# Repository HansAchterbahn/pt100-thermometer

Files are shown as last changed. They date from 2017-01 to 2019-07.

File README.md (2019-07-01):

# pt100-thermometer
_Entwicklungsdaten für ein einfaches elektronisches Thermometer_  

Die Entwicklungsdaten in diesem Repro werden auf meinem Blog https://aetzenloetenprogrammieren.blogspot.com genauer beschrieben.  

## Messprinzip

Abbildung: Messprinzip der Schaltung

## Foto der fertigen Platine

Foto: Gefertigte Platine mit Anschlüssen
Foto: Nahaufnahme der Platine

## Schaltplan

Abbildung: Schaltplan

## Boardlayout

Abbildung: Boardlayout

## Verzeichnisstruktur

* Datenblätter  
 -- AD620.pdf  
 -- TS914.pdf  
* Layout  
 * Eagle  
  -- PT100-SensorPCB008.brd  
  -- PT100-SensorPCB008.sch  
  -- PT100-SensorPCB008-Board.pdf  
  -- PT100-SensorPCB008-Schaltplan.pdf  
 * Fritzing(Breadboard)  
   -- Thermometer-PT100-fritzing.fzz  
   -- Thermometer-PT100-fritzing.png  
* Simulation  
 * LTSpice  
   -- Thermometer-PT100-LTSpice.asc  
   -- Thermometer-PT100-LTSpice.png  
 * Mathematica  
   -- PT100Kennlinie.cdf  
   -- PT100Kennlinie.png  

## Verwendete Programme

__Schaltplan, Leiterplattenlayout und Breadbord:__

Eagle - Erstellen von Schaltplan und Leiterplattenlayout  
http://www.autodesk.com/products/eagle/overview  

Fritzing - Erstellen des Breadbords  
http://fritzing.org/home/  

__Simulation__

LTSpice - Simulation des Schaltplans  
http://www.linear.com/designtools/software/#LTspice  

Mathematica - Animation der Temperaturkennlinie (Kann mit dem kostenlosen Wolfram CDF Player abgespielt werden)  
http://www.wolfram.com/mathematica/  
https://www.wolfram.com/cdf-player/

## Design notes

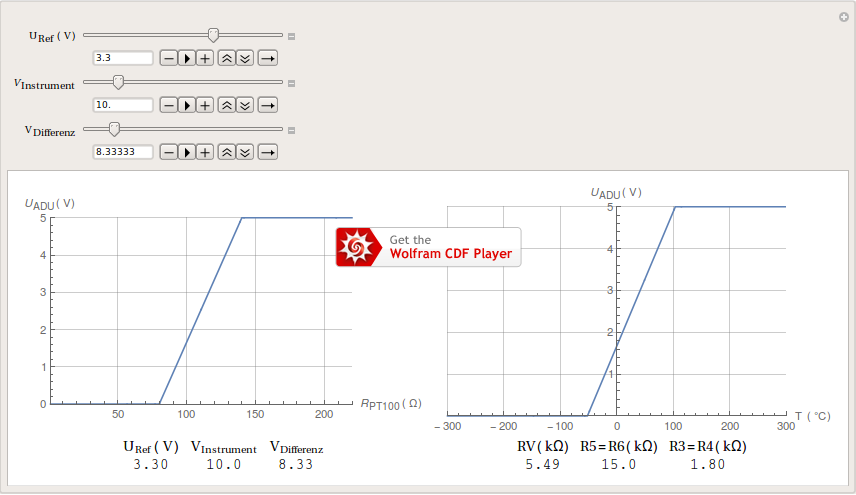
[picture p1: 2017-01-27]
Simulation/Mathematica/PT100Kennlinie.png

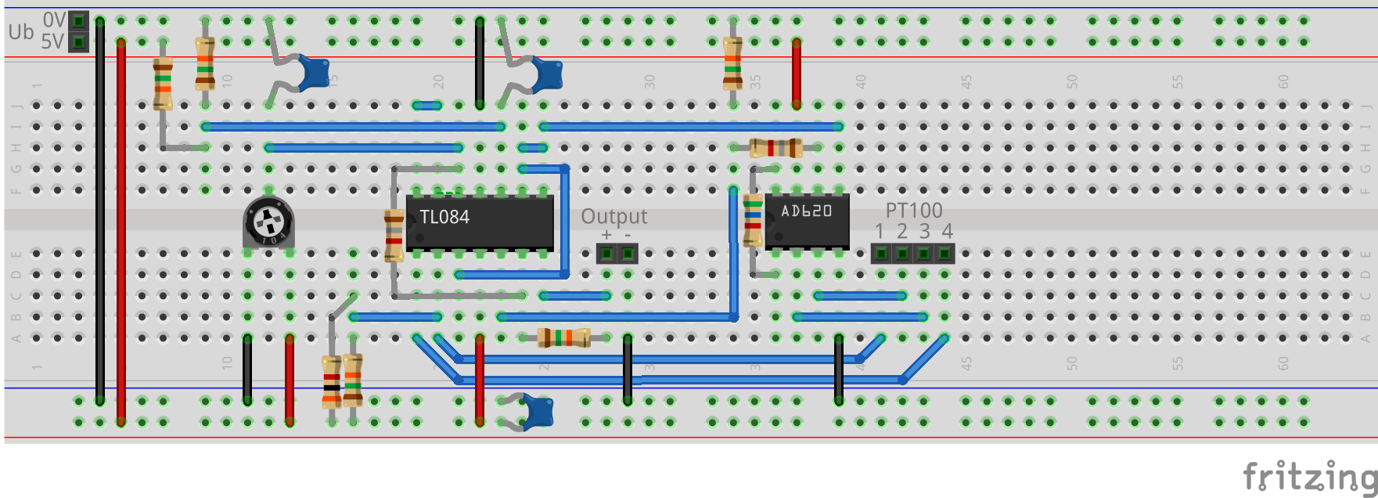
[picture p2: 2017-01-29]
Layout/Fritzing-Breadboard/Thermometer-PT100-Fritzing.png

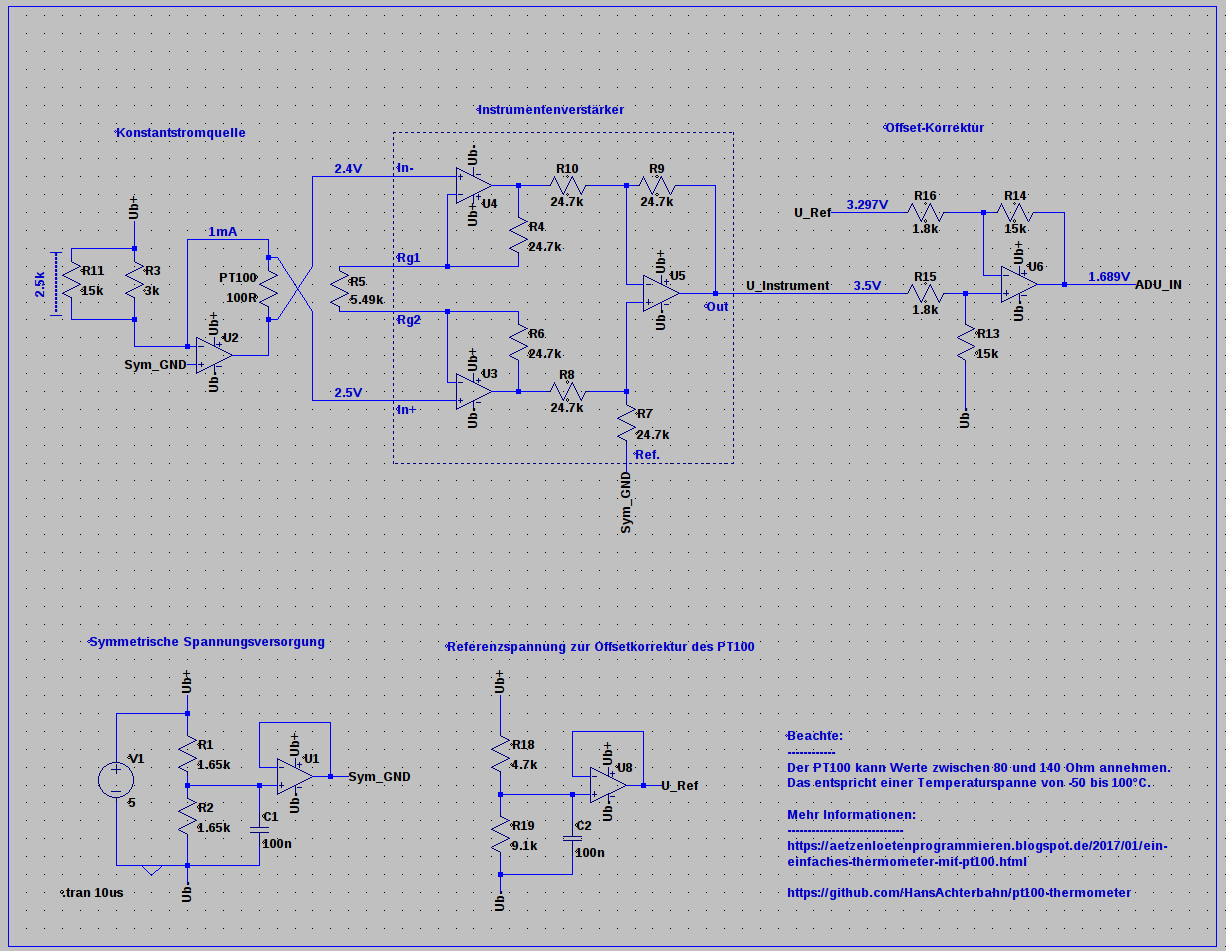
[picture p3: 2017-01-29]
Simulation/LTSpice/Thermometer-PT100-LTSpice.png

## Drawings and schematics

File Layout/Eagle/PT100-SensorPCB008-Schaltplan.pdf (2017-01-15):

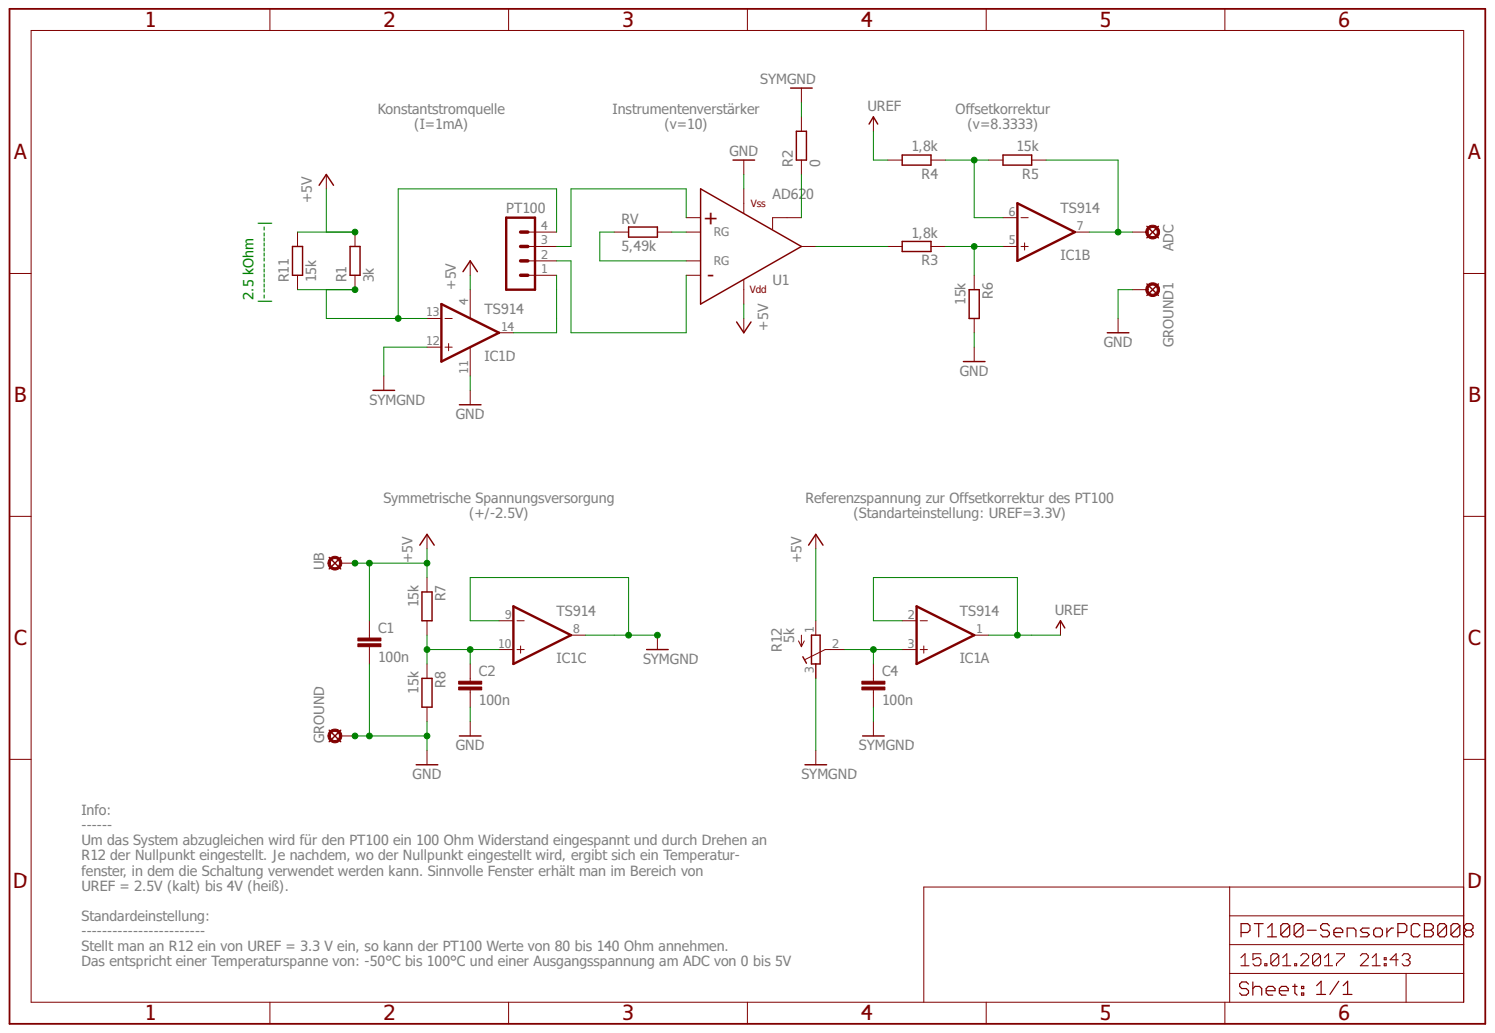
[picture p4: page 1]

SYMGND

Referenzspannung zur Offsetkorrektur des PT100

Info: ------ Um das System abzugleichen wird für den PT100 ein 100 Ohm Widerstand eingespannt und durch Drehen an R12 der Nullpunkt eingestellt. Je nachdem, wo der Nullpunkt eingestellt wird, ergibt sich ein Temperatur-

fenster, in dem die Schaltung verwendet werden kann. Sinnvolle Fenster erhält man im Bereich von UREF = 2.5V (kalt) bis 4V (heiß). Standardeinstellung: ------------------------ Stellt man an R12 ein von UREF = 3.3 V ein, so kann der PT100 Werte von 80 bis 140 Ohm annehmen. Das entspricht einer Temperaturspanne von: -50°C bis 100°C und einer Ausgangsspannung am ADC von 0 bis 5V

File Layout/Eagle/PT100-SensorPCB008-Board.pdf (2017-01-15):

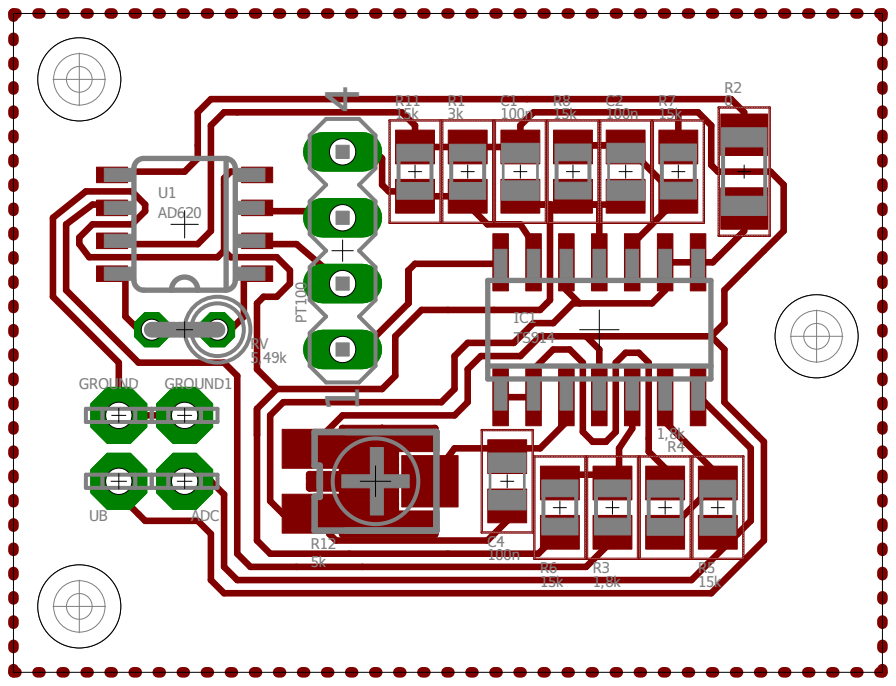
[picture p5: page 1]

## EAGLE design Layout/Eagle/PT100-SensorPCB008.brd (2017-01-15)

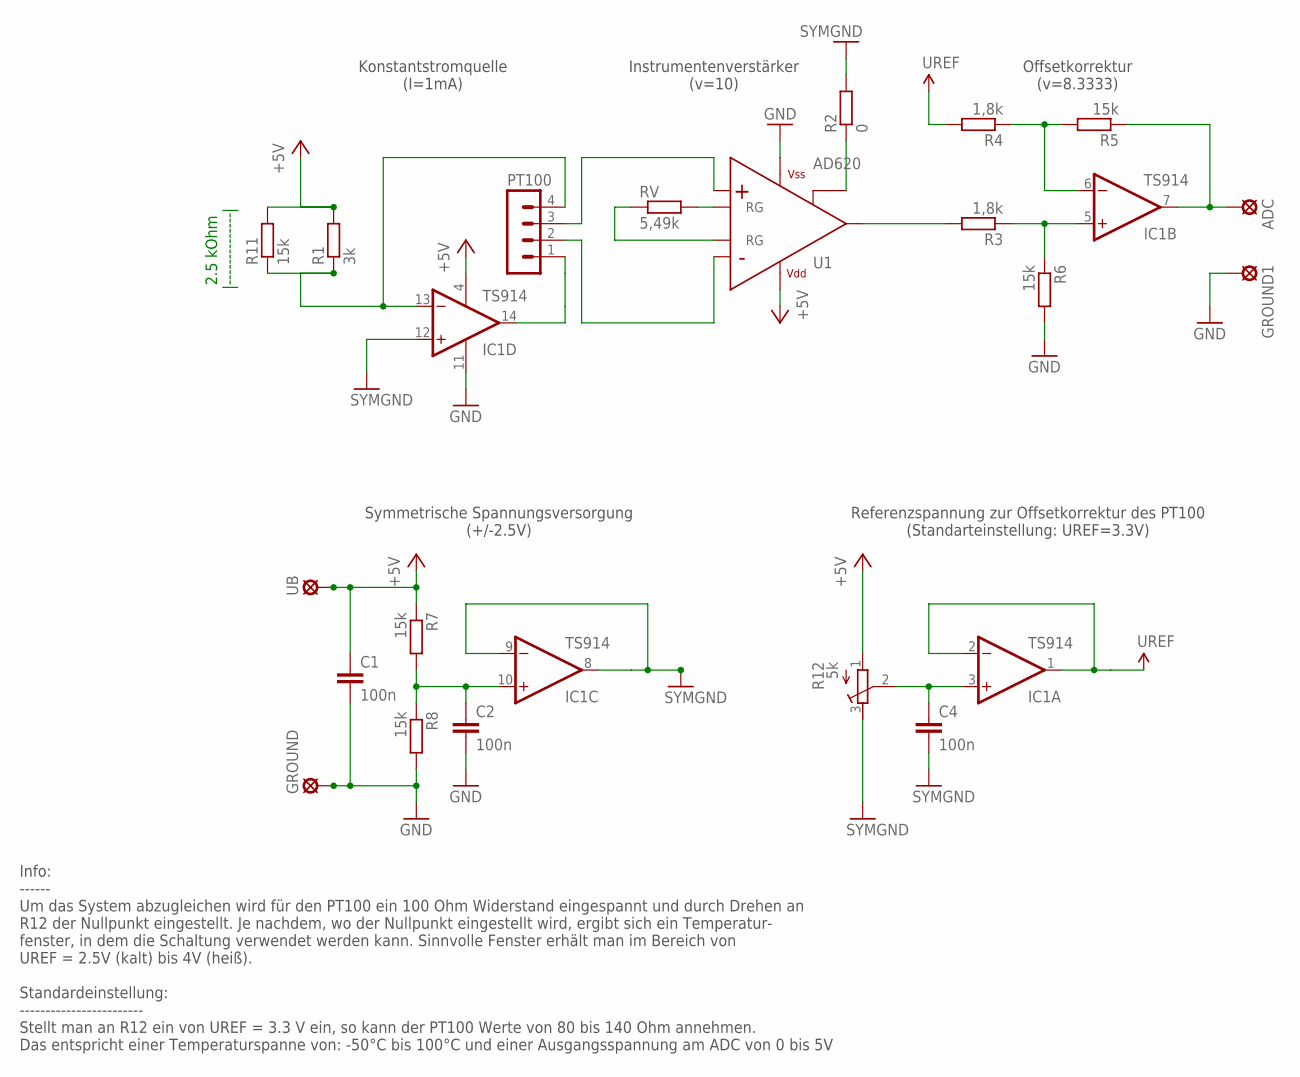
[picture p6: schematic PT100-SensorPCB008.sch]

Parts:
ADC: LSP10
C1, C2, C4: 100n; C0805
GROUND, GROUND1: LSP10
IC1: TS914; SO14
PT100: MA04-1
R1: 3k; R0805
R2: 0; R1206
R3, R4: 1,8k; R0805
R5, R6, R7, R8, R11: 15k; R0805
R12: 5k; RTRIM3374
RV: 5,49k; 0207/2V
U1: AD620; SO08-TIGHT
UB: LSP10

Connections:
+3V3: C1.1, IC1.4 (V+), R1.2, R7.1, R11.2, R12.1 (A), U1.7 (VS+), UB.MP
GND: C1.2, C2.2, GROUND.MP, GROUND1.MP, IC1.11 (V-), R6.2, R8.2, U1.4 (VS-)
INST_A: R3.2, U1.6 (OUTPUT)
INST_E-NEG: IC1.13 (-IN), PT100.4, R1.1, R11.1
INST_E-POS: PT100.2, U1.2 (IN-)
unnamed: RV.2, U1.8 (RG)
unnamed: RV.1, U1.1 (RG)
unnamed: IC1.14 (OUT), PT100.1
unnamed: R2.1, U1.5 (REF)
unnamed: PT100.3, U1.3 (IN+)
unnamed: C4.1, IC1.3 (+IN), R12.2 (S)
unnamed: IC1.6 (-IN), R4.1, R5.2
unnamed: IC1.5 (+IN), R3.1, R6.1
unnamed: ADC.MP, IC1.7 (OUT), R5.1
unnamed: C2.1, IC1.10 (+IN), R7.2, R8.1
SYMGND: C4.2, IC1.8 (OUT), IC1.9 (-IN), IC1.12 (+IN), R2.2, R12.3 (E)
UREF: IC1.1 (OUT), IC1.2 (-IN), R4.2

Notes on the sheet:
2.5 kOhm |--------------|
Konstantstromquelle (I=1mA)
Instrumentenverstärker (v=10)
Offsetkorrektur (v=8.3333)
Symmetrische Spannungsversorgung (+/-2.5V)
Referenzspannung zur Offsetkorrektur des PT100 (Standarteinstellung: UREF=3.3V)
Info: ------ Um das System abzugleichen wird für den PT100 ein 100 Ohm Widerstand eingespannt und durch Drehen an R12 der Nullpunkt eingestellt. Je nachdem, wo der Nullpunkt eingestellt wird, ergibt sich ein Temperatur- fenster, in dem die Schaltung verwendet werden kann. Sinnvolle Fenster erhält m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

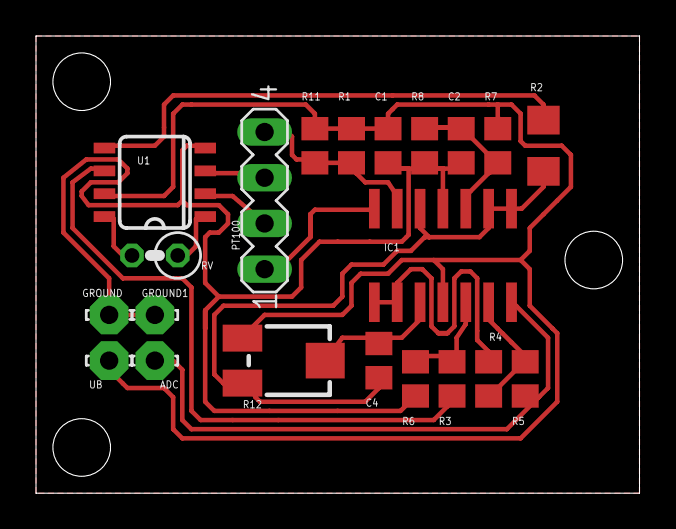
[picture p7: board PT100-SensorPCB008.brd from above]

Board: 2 copper layers, 33.5 x 25.4 mm, 21 parts (0 on the bottom side), 17 nets.

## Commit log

2017-01-15 Eagledaten hinzugefügt Datenblätter hinzugefügt
    [PT100-SensorPCB008.brd, PT100-SensorPCB008.sch]
2017-01-29 Verzeichnisstruktur geändert Simulationsdaten hinzugefügt • Mathematica • LTSpice README Erweitert
    [PT100-SensorPCB008.brd, PT100-SensorPCB008.sch, Thermometer-PT100-Fritzing.fzz]

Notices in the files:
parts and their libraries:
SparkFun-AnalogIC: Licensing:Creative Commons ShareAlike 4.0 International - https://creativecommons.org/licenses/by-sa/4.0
